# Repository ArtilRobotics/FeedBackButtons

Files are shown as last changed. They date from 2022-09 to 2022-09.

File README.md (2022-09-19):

# FeedBackButtons
Un dispositivo IoT para tomar feedback fácilmente.

Coloque la pregunta en el panel de la terminal sonriente con papel y el usuario simplemente ingresa la respuesta presionando uno de los cuatro botones en la terminal. Los botones están codificados en cuatro colores, el verde es "muy feliz", el verde amarillo es "feliz", el rosa es "insatisfecho", el rojo es "muy insatisfecho" y las expresiones se dibujan en los botones

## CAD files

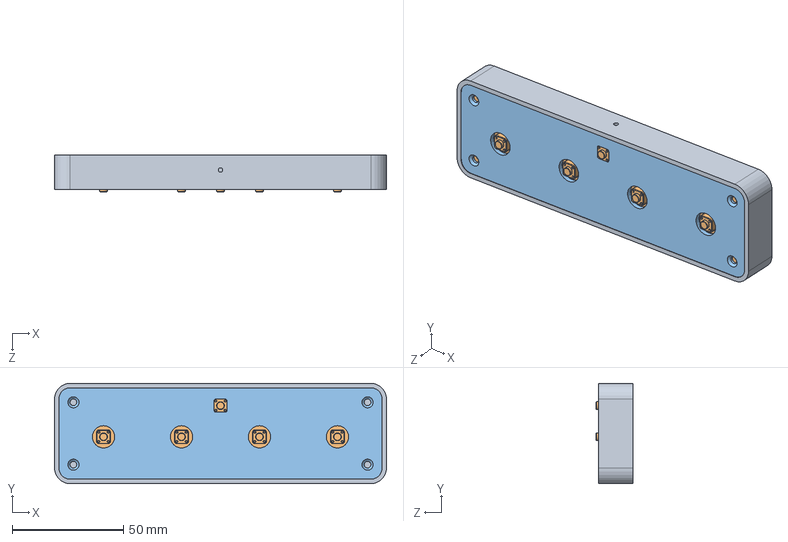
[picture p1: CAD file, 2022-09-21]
Case/EnsamblajeFeedBack.SLDASM
149.0 x 45.0 x 16.5 mm
Case
FeedBackPCB

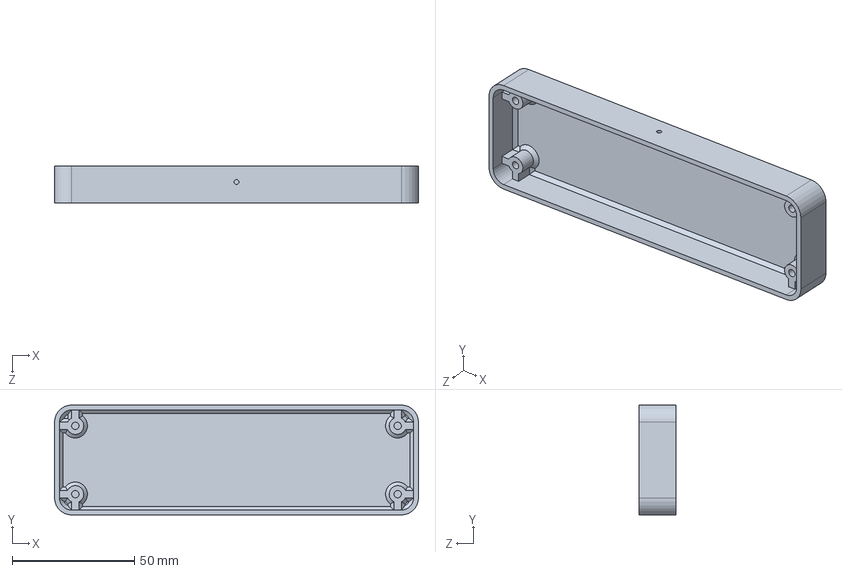
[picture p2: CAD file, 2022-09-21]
Case/Case.SLDPRT
149.0 x 45.0 x 15.4 mm

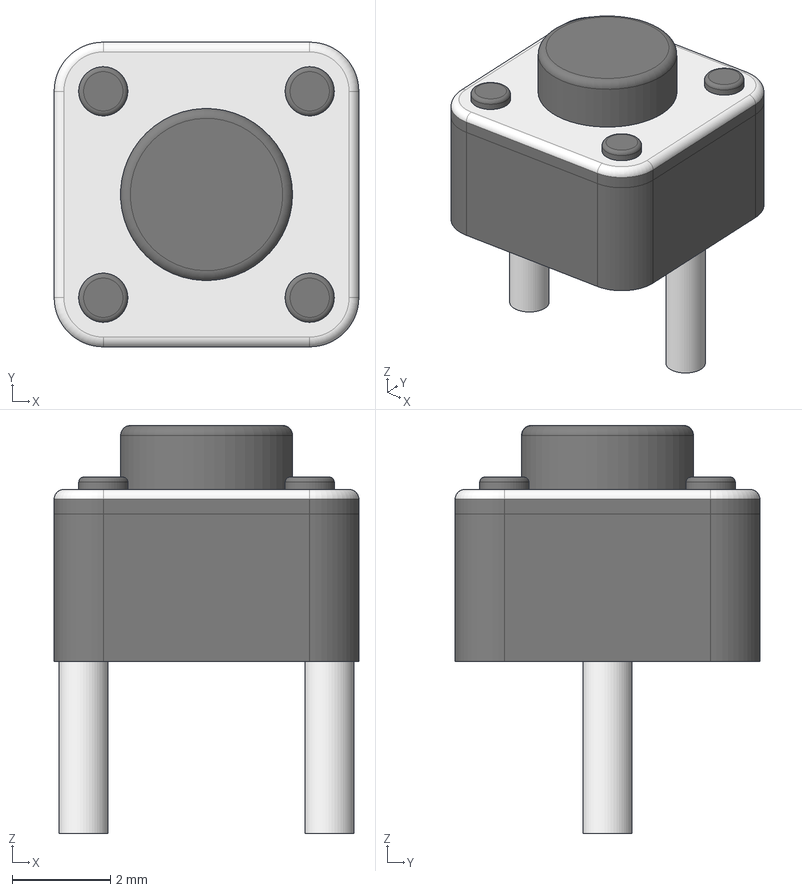
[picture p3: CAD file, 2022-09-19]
Hardware/BUTT-2/boton.step
6.20 x 6.20 x 8.30 mm

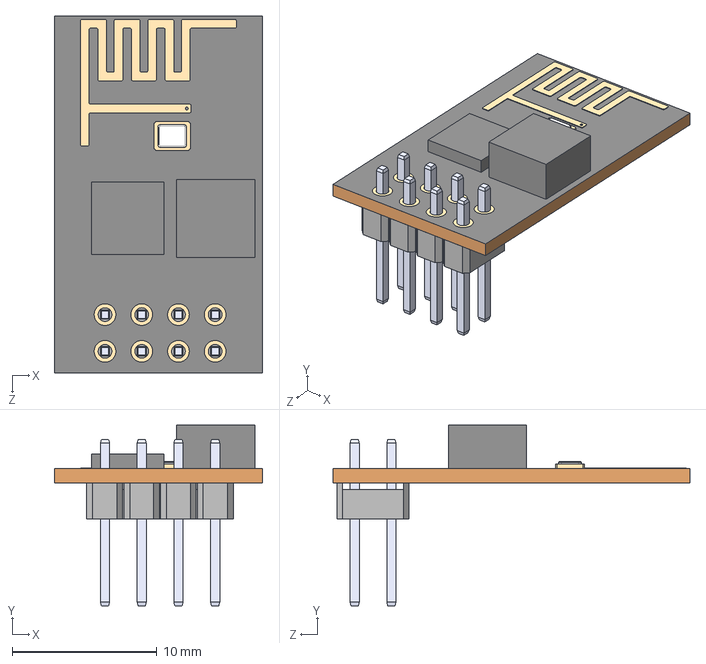
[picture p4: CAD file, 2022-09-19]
Hardware/ESP8266/ESP8266-01_ESP-01.step
14.4 x 12.5 x 24.7 mm

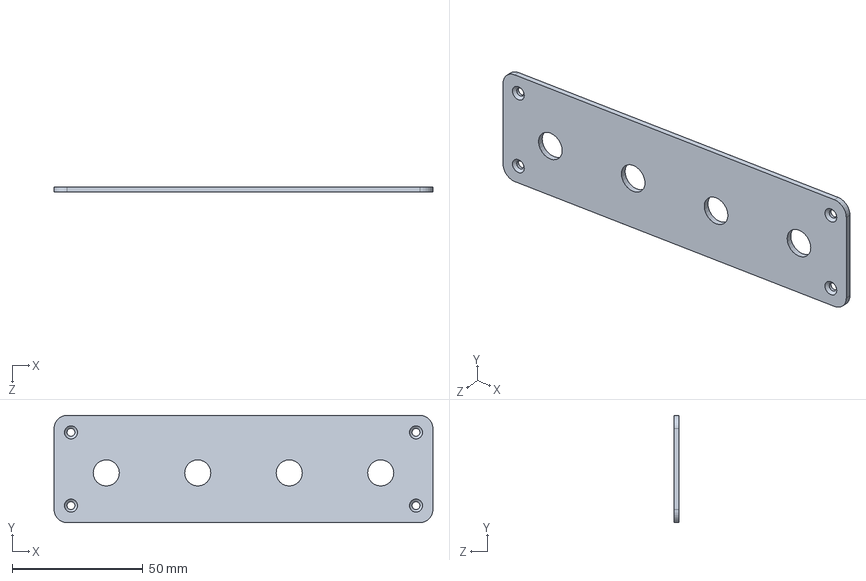
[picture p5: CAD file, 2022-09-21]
Case/Tapa.SLDPRT
145.0 x 41.0 x 2.00 mm

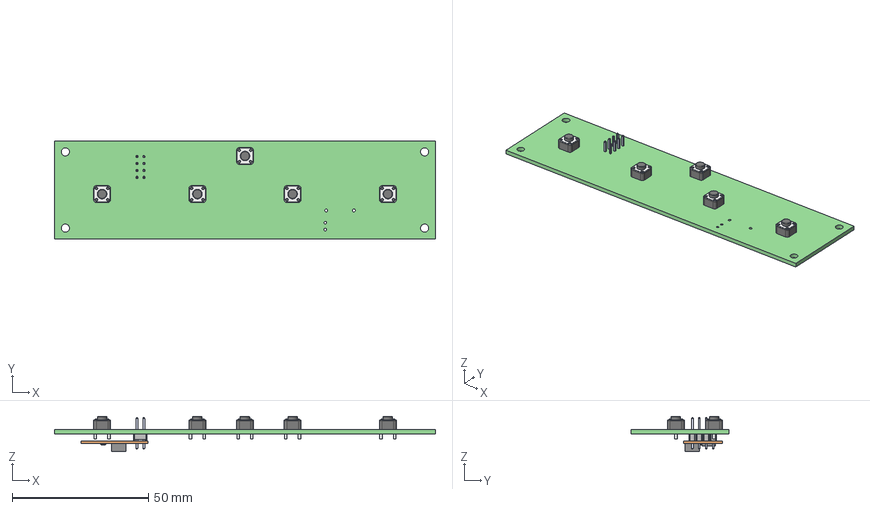
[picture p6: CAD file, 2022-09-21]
Case/FeedBackPCB.step
140.0 x 36.0 x 13.0 mm
FeedBackButtons PCB

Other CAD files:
Case/Case.STL
Case/FeedBackPCB.SLDPRT
Case/Tapa.DXF

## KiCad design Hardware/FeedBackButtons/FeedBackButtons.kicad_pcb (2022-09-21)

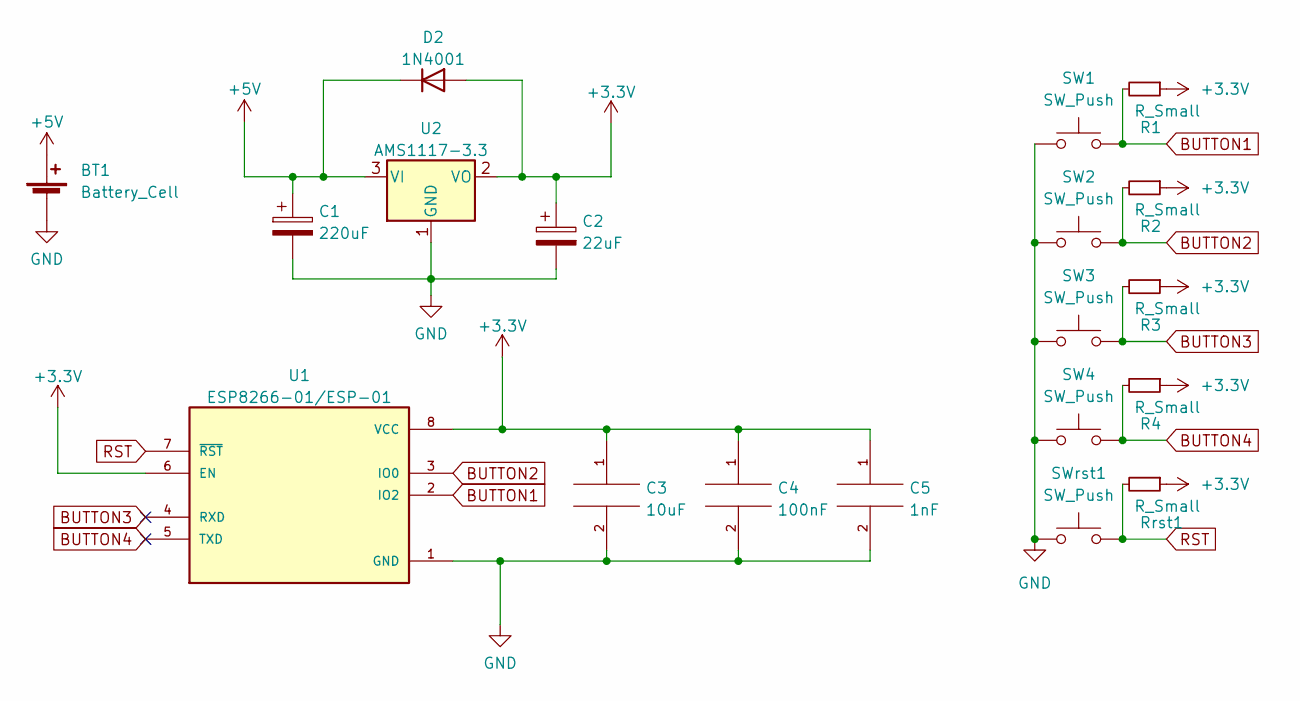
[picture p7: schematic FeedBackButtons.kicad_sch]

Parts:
BT1: Battery_Cell; PinHeader_1x02_P2.54mm_Horizontal
C1: 220uF; C_0805_2012Metric_Pad1.18x1.45mm_HandSolder
C2: 22uF; C_0805_2012Metric_Pad1.18x1.45mm_HandSolder
C3: 10uF; C_0805_2012Metric_Pad1.18x1.45mm_HandSolder
C4: 100nF; C_0805_2012Metric_Pad1.18x1.45mm_HandSolder
C5: 1nF; C_0805_2012Metric_Pad1.18x1.45mm_HandSolder
D2: 1N4001; D_DO-41_SOD81_P10.16mm_Horizontal
R1, R2, R3, R4: R_Small; R_0805_2012Metric_Pad1.20x1.40mm_HandSolder
Rrst1: R_Small; R_0805_2012Metric_Pad1.20x1.40mm_HandSolder
SW1, SW2, SW3, SW4: SW_Push; SW_BUTT-2
SWrst1: SW_Push; SW_BUTT-2
U1: ESP8266-01/ESP-01; XCVR_ESP8266-01_ESP-01; PARTREV V1.2
U2: AMS1117-3.3; SOT-223-3_TabPin2

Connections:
+3.3V: C2.1, C3.1, C4.1, C5.1, D2.2 (A), R1.1, R2.1, R3.1, R4.1, Rrst1.1, U1.6 (EN), U1.8 (VCC), U2.2 (VO)
+5V: BT1.1 (+), C1.1, D2.1 (K), U2.3 (VI)
BUTTON1: R1.2, SW1.2, U1.2 (IO2)
BUTTON2: R2.2, SW2.2, U1.3 (IO0)
BUTTON3: R3.2, SW3.2, U1.4 (RXD)
BUTTON4: R4.2, SW4.2, U1.5 (TXD)
GND: BT1.2 (-), C1.2, C2.2, C3.2, C4.2, C5.2, SW1.1, SW2.1, SW3.1, SW4.1, SWrst1.1, U1.1 (GND), U2.1 (GND)
RST: Rrst1.2, SWrst1.2, U1.7 (~RST)

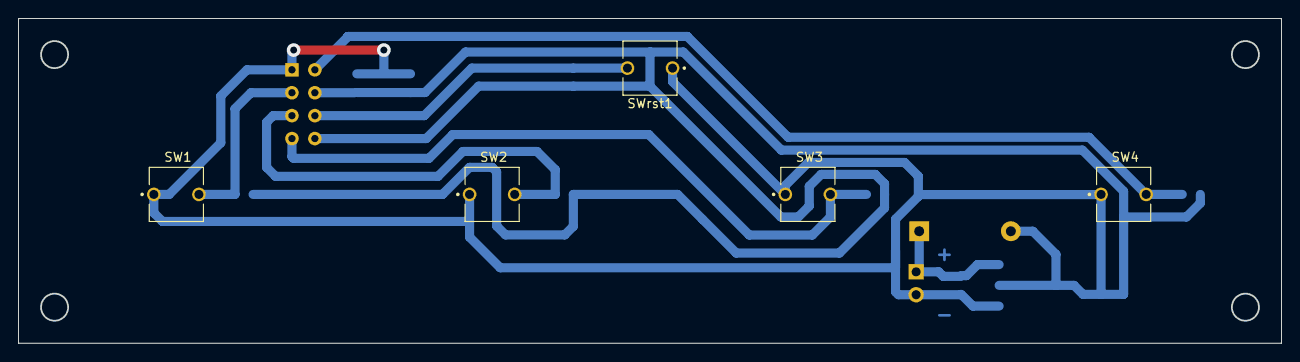
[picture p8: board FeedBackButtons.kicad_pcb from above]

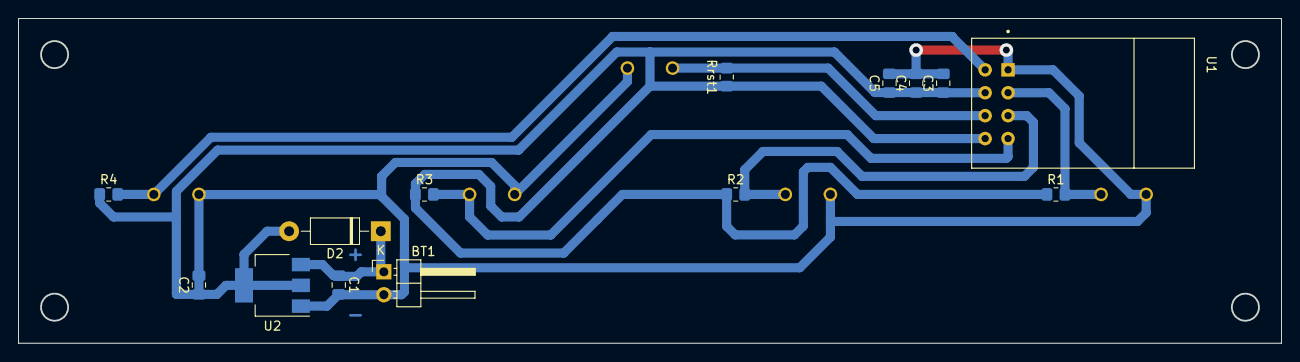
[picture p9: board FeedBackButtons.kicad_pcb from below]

Board: 2 copper layers, 140.0 x 36.0 mm, 19 parts (14 on the bottom side), 8 nets.

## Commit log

2022-09-19 Esquema base desde IoTmd
    [ESP8266-01_ESP-01.step, FeedBackButtons.kicad_pcb, FeedBackButtons.kicad_sch]
2022-09-19 Diseño esquematico y pcb con ruteado
    [FeedBackButtons.kicad_pcb, FeedBackButtons.kicad_sch, boton.step]
2022-09-21 Corrección de Agujeros para sujeción
    [Case.SLDPRT, FeedBackButtons.kicad_pcb, FeedBackPCB.SLDPRT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]
2022-09-21 Genere los Gerbers para fabricacion Demo V1
    [FeedBackButtons.kicad_pcb]
2022-09-21 ensamble final y DFX
    [Case.SLDPRT, Case.STL, EnsamblajeFeedBack.SLDASM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]
